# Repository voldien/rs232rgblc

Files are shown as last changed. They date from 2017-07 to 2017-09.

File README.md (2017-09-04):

# RS232RGBLEDController #
-----

The *RS232RGBLEDController* is extension PCB board for motherboard. Where its connected via the *com port* and the 12V rail. Where a LED strip can be either connected via the RGB headers or the 12V+, GND and data pin. Where it RGB has dedicated pin for RGB and GND. Whereas the other one uses SPI to communicated with LED strip. 

Remark that the schematic and PCB layout and the software driver are still work in progress and has yet not been tested!

## Motivation ##
----
The project was created in order to take advantages of the *com port* commonly found on motherboard, which is seldom used by the majority of desktop user.

The board is intended to add support for a cheap alternative for RGB lightning for desktop computers.

## Installation ##
------
The following section covers how the install the driver on the destkop in order to communicate with the extension board from *userspace*. Where the library for interfacing with the board will be installed along with a command line program, which can alter the behavior of the board in runtime.

## Unix ##
The driver for *UNIX* system can be installed as followed:
```
make 
make install
```

## Examples ##
-----

## License ##
---
The source code for this project is licensed under the GPL+3 License - see the [LICENSE](LICENSE) file for details.
The hardware design for this project is under the OSHW License - See [](LICENSE) for more detials.

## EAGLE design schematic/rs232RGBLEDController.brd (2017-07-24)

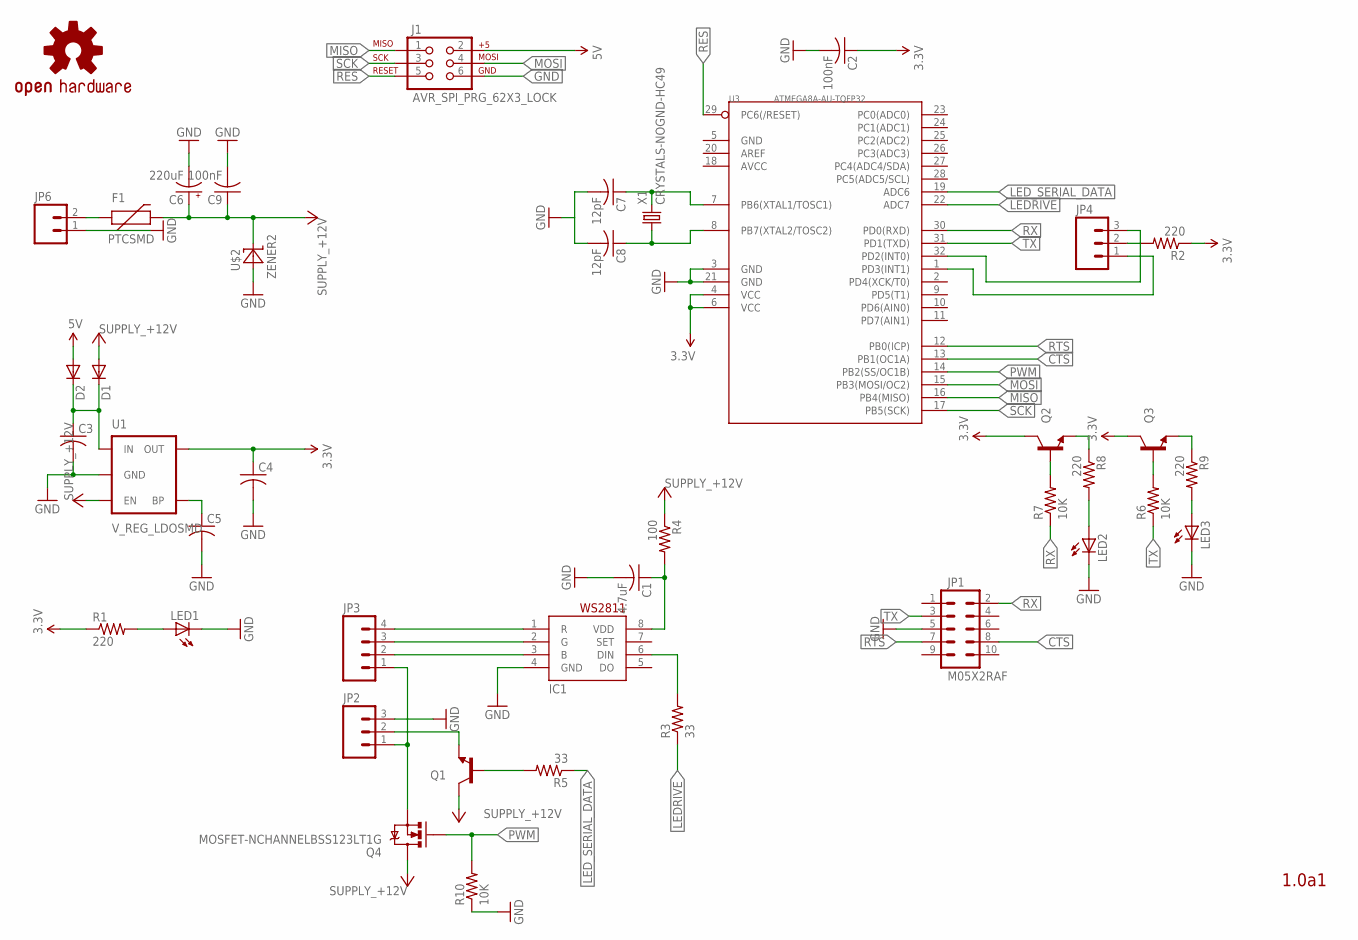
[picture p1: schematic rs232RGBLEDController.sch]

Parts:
C1: 4.7uF; C0603
C2, C9: 100nF; C0603
C3, C4, C5: C-USC0603; C0603
C6: 220uF; 175TMP-0810
C7, C8: 12pF; C0603
D1, D2: DIODESOT23; SOT23-3
F1: PTCSMD; PTC-1206
IC1: WS2811-SOP8; SO08-SKINNYPADS
J1: AVR_SPI_PRG_62X3_LOCK; 2X3_LOCK
JP1: M05X2RAF; 2X5-RAF
JP2, JP4: M03PTH; 1X03
JP3: M04PTH; 1X04
JP6: M021X02_NO_SILK; 1X02_NO_SILK
LED1, LED2, LED3: LED0603; LED-0603
Q1, Q2, Q3: TRANSISTOR_NPNSOT23; SOT23
Q4: MOSFET-NCHANNELBSS123LT1G; SOT23-3
R1, R2, R8, R9: 220; R0603
R3, R5: 33; R0603
R4: 100; R0603
R6, R7, R10: 10K; R0603
U1: V_REG_LDOSMD; SOT23-5
U3: ATMEGA8A-AU-TQFP32; TQFP32-0.8-7X7MM
U$1: OSHW-LOGOS; OSHW-LOGO-S
U$2: ZENER2; SOD123
X1: CRYSTALS-NOGND-HC49; HC49

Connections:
3.3V: C2.1, C4.1, Q2.3 (C), Q3.3 (C), R1.1, R2.1, U1.5 (OUT), U3.4 (VCC), U3.6 (VCC)
5V: D2.1 (A), J1.2
+12V: C6.+, C9.1, D1.1 (A), F1.2, Q1.3 (C), Q4.3 (D), R4.1, U1.3 (EN), U$2.C
CTS: JP1.8, U3.13 (PB1(OC1A))
GND: C1.2, C2.2, C3.2, C4.2, C5.2, C6.-, C7.2, C8.2, C9.2, IC1.4 (GND), J1.6, JP1.5, JP2.3, JP6.1, LED1.C, LED2.C, LED3.C, R10.1, U1.2 (GND), U3.3 (GND), U3.21 (GND), U$2.A
LEDRIVE: R3.1, U3.22 (ADC7)
LED_SERIAL_DATA: R5.1, U3.19 (ADC6)
MISO: J1.1, U3.16 (PB4(MISO))
MOSI: J1.4, U3.15 (PB3(MOSI/OC2))
unnamed: Q2.1 (B), R7.2
unnamed: C3.1, D1.3 (C), D2.3 (C), U1.1 (IN)
unnamed: Q3.1 (B), R6.2
unnamed: Q2.2 (E), R8.1
unnamed: LED2.A, R8.2
unnamed: JP2.1, JP3.1, Q4.2 (S)
unnamed: Q3.2 (E), R9.1
unnamed: LED3.A, R9.2
unnamed: JP2.2, Q1.2 (E)
unnamed: LED1.A, R1.2
unnamed: IC1.3 (B), JP3.2
unnamed: C5.1, U1.4 (BP)
unnamed: C8.1, U3.8 (PB7(XTAL2/TOSC2)), X1.1
unnamed: C7.1, U3.7 (PB6(XTAL1/TOSC1)), X1.2
unnamed: JP4.2, R2.2
unnamed: JP4.1, U3.1 (PD3(INT1))
unnamed: JP4.3, U3.32 (PD2(INT0))
unnamed: IC1.2 (G), JP3.3
unnamed: IC1.1 (R), JP3.4
unnamed: IC1.6 (DIN), R3.2
unnamed: C1.1, IC1.8 (VDD), R4.2
unnamed: Q1.1 (B), R5.2
unnamed: F1.1, JP6.2
PWM: Q4.1 (G), R10.2, U3.14 (PB2(SS/OC1B))
RES: J1.5, U3.29 (PC6(/RESET))
RTS: JP1.7, U3.12 (PB0(ICP))
RX: JP1.2, R7.1, U3.30 (PD0(RXD))
SCK: J1.3, U3.17 (PB5(SCK))
TX: JP1.3, R6.1, U3.31 (PD1(TXD))

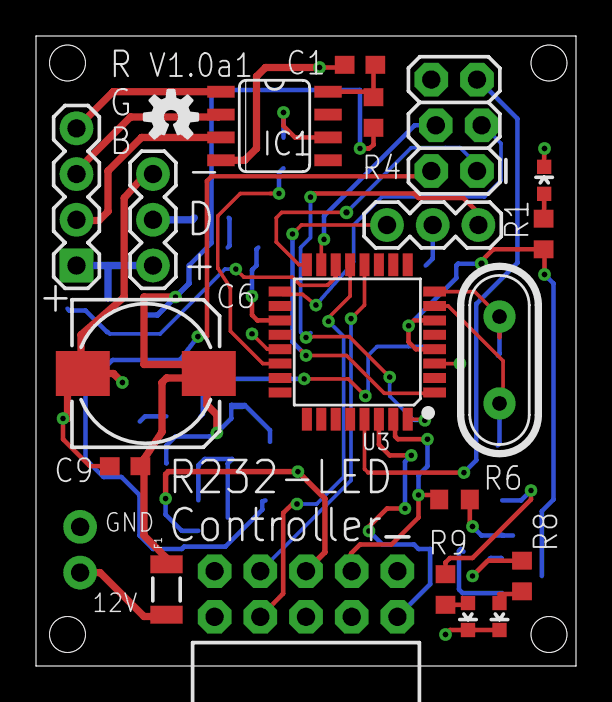
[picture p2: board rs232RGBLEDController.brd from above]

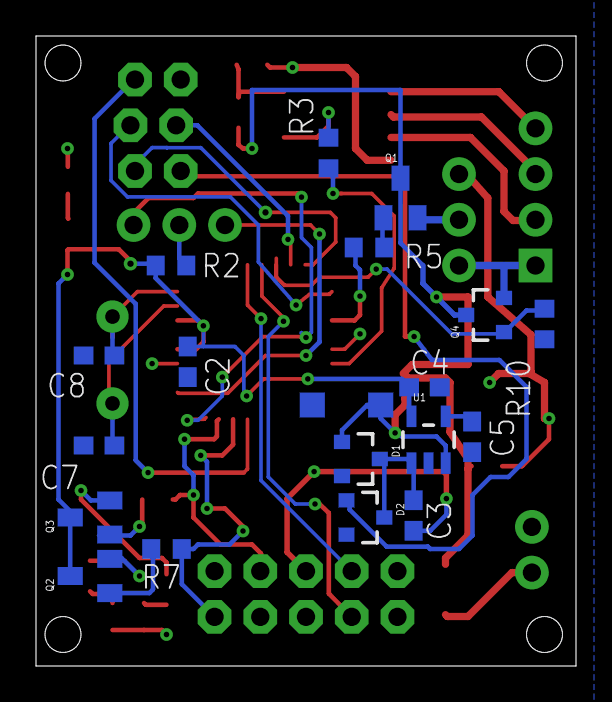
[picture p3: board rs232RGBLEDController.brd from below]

Board: 2 copper layers, 30.0 x 35.0 mm, 41 parts (19 on the bottom side), 38 nets.

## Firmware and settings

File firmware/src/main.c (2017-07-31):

#include"r232lc.h"
#include"queue.h"
#include"uart.h"
#include"spi.h"
#include"anim.h"
#include"pwm.h"
#include"protocol.h"
#include<avr/wdt.h>

#include<avr/io.h>
#include<avr/interrupt.h>
#include<avr/fuse.h>
#include<avr/pgmspace.h>
#include<avr/sleep.h>
#include<stdio.h>
#include<avr/lock.h>
#include<avr/cpufunc.h>

/**
 *
 */
const uint8_t PROGMEM statepin0 = PB6;
const uint8_t PROGMEM statepin1 = PB7;
const uint8_t PROGMEM sckpin = PB5;
const uint8_t PROGMEM mosipin = PB4;
const uint8_t PROGMEM misopin = PB3;
const uint8_t PROGMEM rxpin = PD0;
const uint8_t PROGMEM txpin = PD1;
const uint8_t PROGMEM ledserpin = PD2;
const uint8_t PROGMEM leddripin = PD3;
const uint8_t PROGMEM pwmpin = PB2;

/**
 *	Define global variable.
 */
volatile transmit_callback g_state_cb = NULL;
volatile struct queue_t rx_queue = {
	.size = 64,
};
volatile struct queue_t tx_queue = {
	.size = 16,
};
volatile struct queue_t led_queue = {
	.size = 32,
};
volatile struct animation_playback_t g_anim = {0};

volatile struct r232_state_t g_state = {
	.hstate = 0,
	.lstate = 0,
};

/**
 *	Fuses for the state of the microntroller through out
 *	the life time.
 */
FUSES =
{
	.low = LFUSE_DEFAULT,
	.high = HFUSE_DEFAULT,
};

/**
 *	Lock
 */
unsigned char __lock __attribute__((section (".lock"))) =
        (LB_MODE_1 & BLB0_MODE_3 & BLB1_MODE_4);



/*	TODO MOVE.	*/
void transmit_rgb_w2811(uint8_t r, uint8_t g, uint8_t b){
	spi_putchar(r);
	spi_putchar(g);
	spi_putchar(b);
}
void transmit_rgb_spidata(uint8_t r, uint8_t g, uint8_t b){
	spi_putchar(r);
	spi_putchar(g);
	spi_putchar(b);
}

/**
 *
 */
ISR(TIMER0_OVF_vect){

	/*	Check if SPI is ready.	*/
	if(spi_ready())
		return;

	/*	requires three bytes.	*/
	if(queue_size(&led_queue) < 3)
		return;

	uint8_t r,g,b;

	if(g_state.lstate & STATE_ANIM){
		/*	Load RGB from animation playback.	*/
		animation_get_next_rgb(&g_anim, &r, &g, &b);
	}else{
		/*	Load RGB from LED data queue.	*/
		r = queue_dequ(&led_queue);
		g = queue_dequ(&led_queue);
		b = queue_dequ(&led_queue);
	}

	/*	transmit.	*/
	g_state_cb(r,g,b);
}

/**
 *
 */
ISR(SPI_STC_vect){
	uint8_t de = queue_dequ(&led_queue);
	spi_directwrite(de);
}

ISR(USART_TXC_vect){
	/*	*/
	if(!queue_empty(&tx_queue)){
		uart_putchar( queue_dequ(&tx_queue) );
	}
}
ISR(USART_RXC_vect){

	/*	Recv next byte.	*/
	queue_enqu(&rx_queue, uart_direct_getchar());
	sleep_disable();
}

ISR(USART_UDRE_vect){

}


ISR(INT0_vect){
	g_state.hstate = STATE_USEW2811;
	g_state_cb = transmit_rgb_w2811;
}

ISR(INT1_vect){
	g_state.hstate = STATE_LED_DATA;
	g_state_cb = transmit_rgb_spidata;
}

int main(void){

	/*	Disable global interrupt.	*/
	cli();

	/*	Disable Watchdog timer.	*/
	wdt_disable();

	/*	Enable UART.	*/
	uart_init();
	uart_enable_interrupt();
	PORTD |= (1 << rxpin) | (1 << txpin);
	DDRD |= (1 << rxpin) | (1 << txpin);

	/*	Enable SPI.	*/
	spi_init();
	spi_enable_interrupt();
	PORTB |= (1 << sckpin) | (1 << mosipin) | (1 << misopin);
	DDRB |= (1 << sckpin) | (1 << mosipin) | (1 << misopin);

	/*	initialize queue.	*/
	init_queue(&rx_queue);
	init_queue(&tx_queue);
	init_queue(&led_queue);

	/*	state.	*/
	PORTD |= (1 << statepin0) | (1 << statepin1);
	DDRD &= ~((1 << statepin0) | (1 << statepin1));
	if(PIND & ( 1 << statepin0) ||
			PIND & ( 1 << statepin1)){
		g_state_cb = transmit_rgb_spidata;
	}else{
		g_state_cb = transmit_rgb_w2811;
	}

	/*	Enable external interrupt.	*/
	MCUCR |= (1 << ISC00) | (1 << ISC01) | (1 << ISC10) | (1 << ISC11);
	GIFR |= (1 << INTF0) | (1 << INTF1);


	/*	Timer interrupt.	*/
	TCCR0 |= (0 << CS02) | (0 << CS01) | (1 << CS02);
	TIMSK |= (1 << TOIE0);

	/*	Create default animation.	*/
	animation_create(&g_anim, 0);

	/*	PWM.	*/
	pwm_enable();
	PORTB |= ( 1 << pwmpin);
	DDRB |= ( 1 << pwmpin);

	/*	LED drive.	*/
	PORTC = (1 << leddripin) | (1 << ledserpin);

	/*	Watchdog for preventing the device from getting stuck.	*/
	wdt_enable( ((1 << WDP2) | (1 << WDP1) | (1 << WDP0)) );

	/*	Enable global interrupt.	*/
	sei();

	/*	Main loop.	*/
	while(1){
		/*	Sleep intill needed.	*/
		set_sleep_mode(SLEEP_MODE_PWR_SAVE);
		sleep_cpu();

		/*	Process command from RX UART.	*/
		while(!queue_empty(&rx_queue)){
			uint8_t buf = queue_dequ(&rx_queue);
			uint8_t com = get_command(buf);
			call_command(com, buf);
		}
	}

	return 0;
}

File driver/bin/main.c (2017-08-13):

/**
    rs232 RGB LED controller binary
    Copyright (C) 2017  Valdemar Lindberg

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
*/
#include<rs232lc/r232lc.h>
#include<stdio.h>
#include<stdlib.h>
#include<getopt.h>
#include<unistd.h>
#include<fcntl.h>
#include<errno.h>
#include<string.h>

int main(int argc,  char *const * argv){

	/*	*/
	int fd;
	int c;
	int index;
	char buf[3];
	size_t len;
	const char* path = "/dev/ttyS";
	RS232LC state;
	int fd = STDIN_FILENO;
	
	/*	*/
	static struct option longoption[] = {
			{"version",	no_argument,		NULL,	'v'},	/*	Print version of the driver library version.	*/
			{"device",	required_argument,	NULL,	'd'},	/*	Override the default character device.	*/
			{"file",	required_argument,	NULL,	'f'},	/*	Override the pipe file descriptor.	 */
			{NULL,		no_argument,		NULL,	0},
	};

	/*	Iterate through each option.	*/
	const char* const shortopt = "dv";
	while((c = getopt_long(argc, argv, shortopt, &index, &longoption))){
		switch(c){
		case 'v':
			printf("version %s.\n", rs232_version());
			exit(EXIT_SUCCESS);
			break;
		case 'd':
			path = optarg;
			break;
		case 'f':
			if(optarg){
				fd = open(optarg, O_RDONLY);
				if(fd < 0){
					fprintf(stderr, "failed open %s, %s.\n", optarg, strerror(errno));
					exit(EXIT_FAILURE);
				}
			}
			break;
		default:
			break;
		}
	}
	
	/*	Open file.	*/
	fd = open(path, O_RDONLY);
	if(fd < 0){
		fprintf(stderr, "failed open %s, %s.\n", path, strerror(errno));
		return EXIT_FAILURE;
	}

	/*	Initialize driver.	*/
	if(!rs232lc_init(&state, fd))
		return EXIT_FAILURE;

	/*	Read each byte.	*/
	if(isatty(STDIN_FILENO)){
		while(read(fd, buf, 3) > 0){
			rs232lc_set_rgb(&state, R232LC_RGB(buf[0], buf[1], buf[2]));
		}
	}

	/*	Release and close driver.	*/
	rs232lc_close(state);
	close(fd);

	/*	Exit.	*/
	return EXIT_SUCCESS;
}

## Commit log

2017-07-24 Added init schematic and boardlayout.
    [rs232RGBLEDController.brd, rs232RGBLEDController.sch]
2017-08-13 Started adding driver for UNIX platforms. The Code has yet not been tested.

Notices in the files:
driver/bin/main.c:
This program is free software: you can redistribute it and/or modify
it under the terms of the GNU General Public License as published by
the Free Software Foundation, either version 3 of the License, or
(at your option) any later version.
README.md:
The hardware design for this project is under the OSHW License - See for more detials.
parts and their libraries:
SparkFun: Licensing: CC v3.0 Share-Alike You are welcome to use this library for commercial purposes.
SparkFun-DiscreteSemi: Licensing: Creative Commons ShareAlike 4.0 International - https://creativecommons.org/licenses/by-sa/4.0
